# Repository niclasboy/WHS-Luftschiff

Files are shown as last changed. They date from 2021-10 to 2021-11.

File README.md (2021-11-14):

# WHS-Luftschiff

Dieses Projekt dokumentiert den Bau eines Starrluftschiffes im Rahmen des Studienganges Elektrotechnik an der Westfälischen Hochschule Gelsenkirchen.

# Mechanik / Aufbau Luftschiff

Dass Luftschiff wird durch vier Motoren angetriebe. Die Motoren sind an Propellergondeln montiert. So lassen die Motoren um -+90° im Bezug zur Hauptachse bewegen. Dank der Motoren ist der Einsatz eines Leitwerkes nicht erforderlich, da die hinteren zwei Motoren diese Aufgabe übernehmen können. Auch können alle Motoren senkrecht zum Luftschiff geneigt werden(90°). Dies kann dazu genutzt werden, um den Auftrieb zu erhöhen bzw. zu verringen. Im Falle eines Ausfalls der Funkverbindung können so die Motoren automatisch senkrecht zum Luftschiff geneigt werden, um das Luftschiff zum sinken zu "zwingen". 

Das Luftschiff besteht aus einem Holzgerippe, welches mit einer dünnen Folie luftdicht verschlossen ist. Um die dichtigkeit weiter zu steigen, beinhaltet das Luftschiff einen innen Körper, welcher später mit Helium/Ballongas gefüllt wird. Dies hat zusätlcih den Vorteil, dass sich im Luftschiff reines Helium befindet.

# Elektronik / Flugsteuerung

https://github.com/niclasboy/Flugsteuerung

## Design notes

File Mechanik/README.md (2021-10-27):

Berechnung des Gewichts / Auftriebs:

-800 gr Luftschiffkonstruktion <br>
-20  gr Innenballon <br>
-160 gr Motoren + Aufhängnung <br>

+1100gr (1200 gr max) Auftrieb <br>
+-------------------------------------------+<br>
120gr für Akku, Flugsteuerung und Kabel

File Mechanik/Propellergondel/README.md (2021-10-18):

Dokumente für den Bau der Propellergondel .

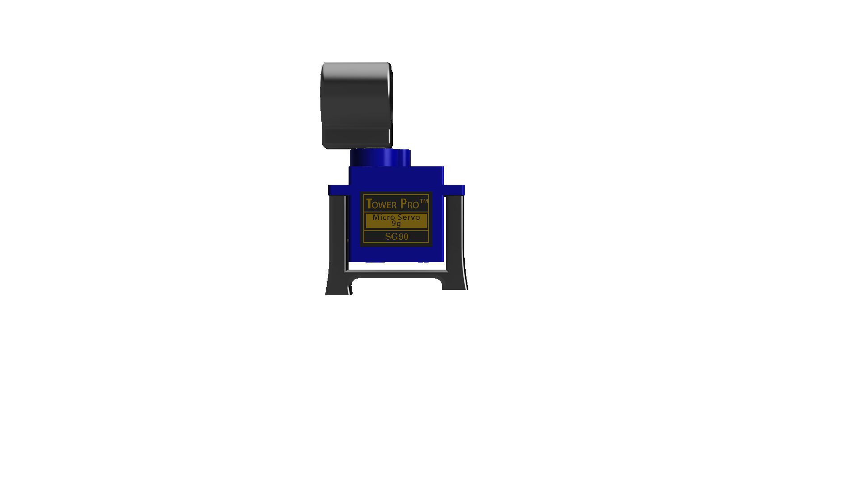
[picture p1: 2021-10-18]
Mechanik/Propellergondel/Bild2.png

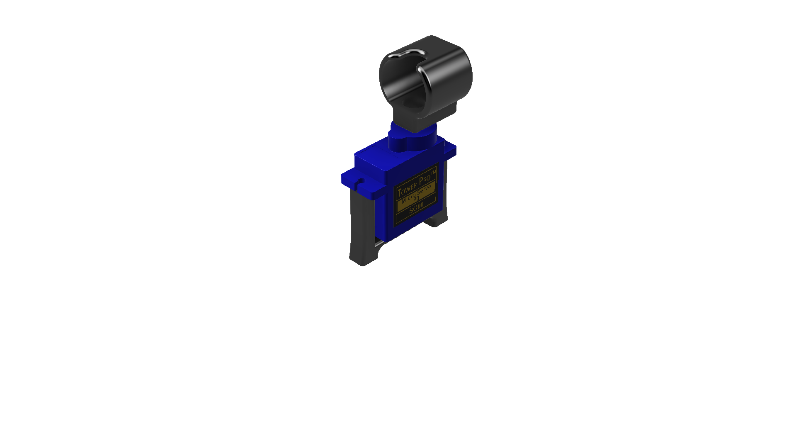
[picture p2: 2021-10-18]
Mechanik/Propellergondel/Bild3.png

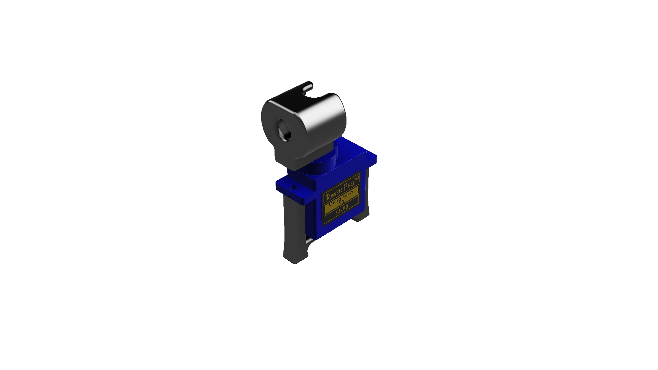
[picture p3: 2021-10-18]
Mechanik/Propellergondel/Bild 1.png

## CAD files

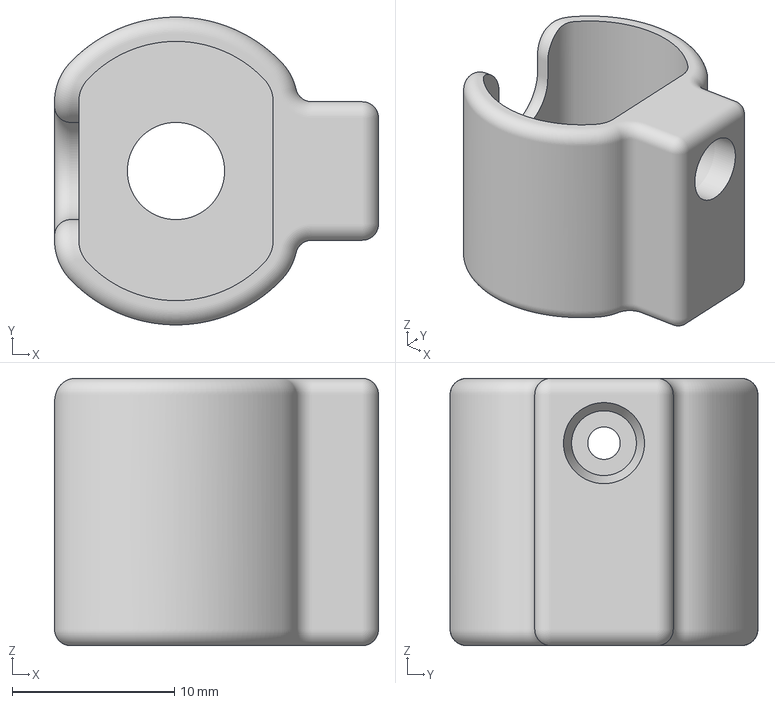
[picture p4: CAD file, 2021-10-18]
Mechanik/Propellergondel/Motorhalterung.3mf
20.0 x 19.0 x 16.5 mm

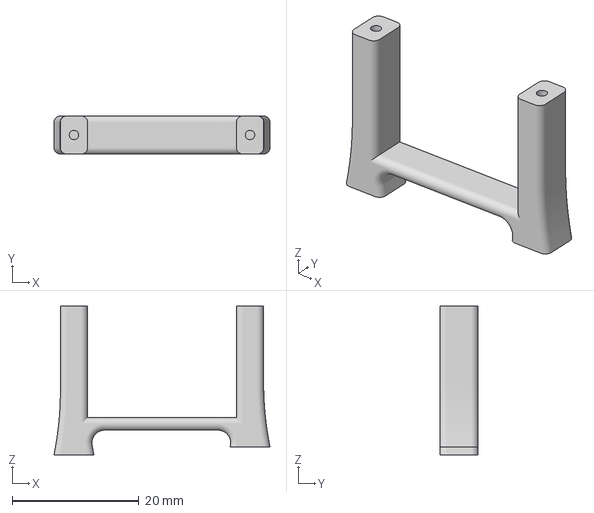
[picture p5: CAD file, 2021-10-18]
Mechanik/Propellergondel/Haupthalterung.3mf
34.1 x 6.00 x 23.5 mm

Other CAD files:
Mechanik/Propellergondel/Propellergondel .f3z

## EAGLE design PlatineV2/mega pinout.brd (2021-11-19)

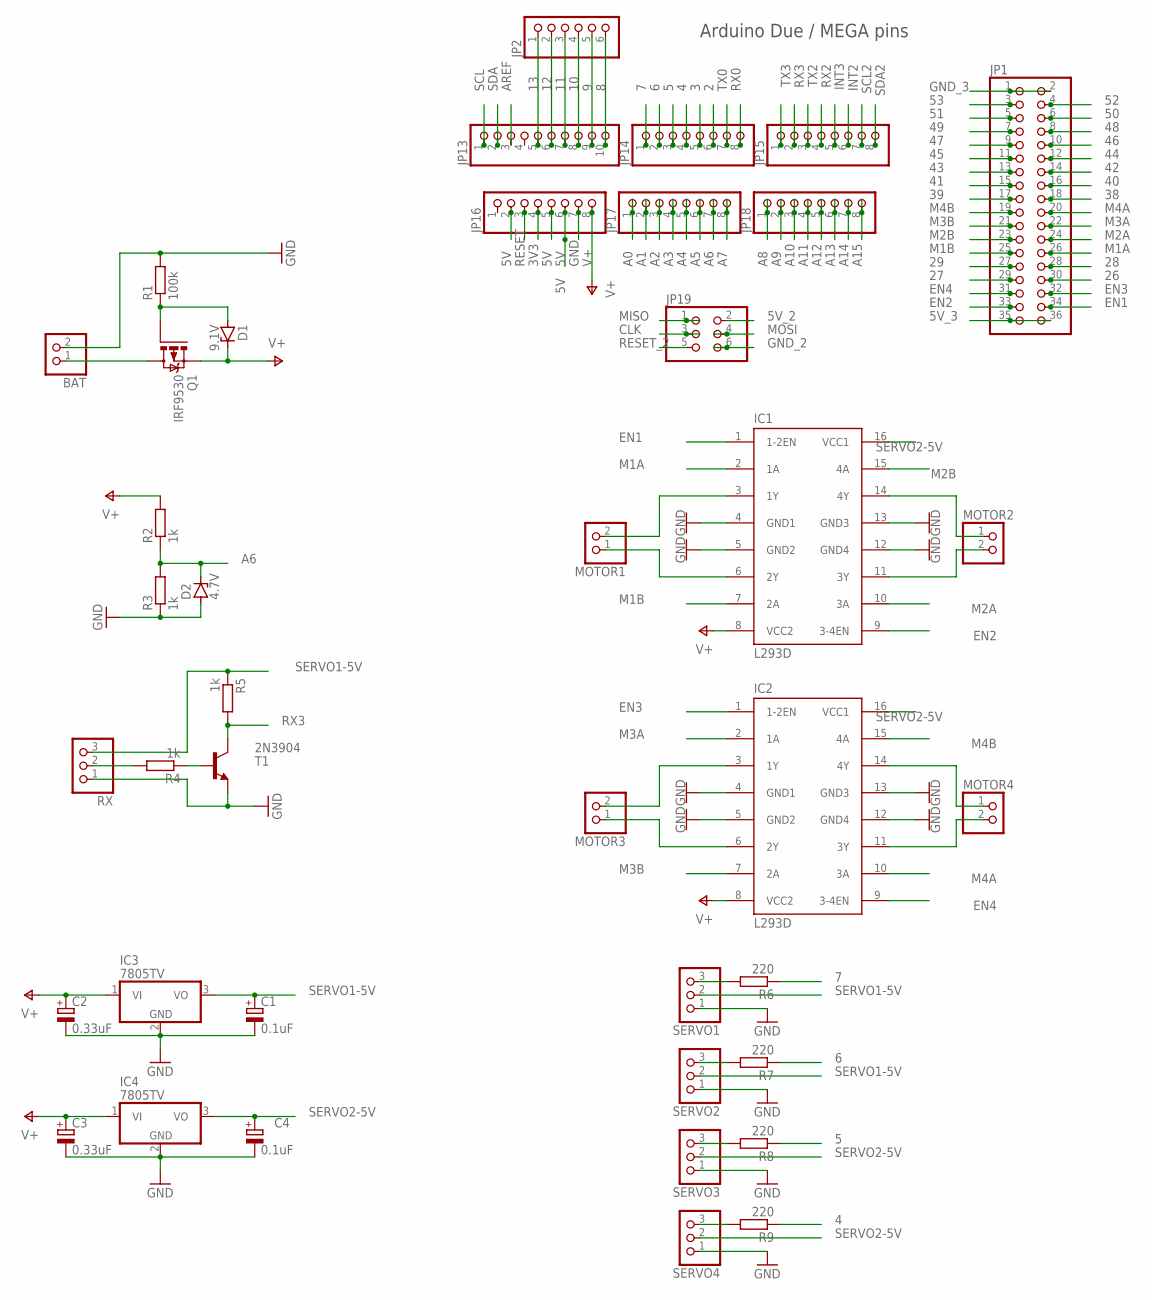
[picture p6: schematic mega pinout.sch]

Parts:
BAT: PINHD-1X2; 1X02
C1, C4: 0.1uF; E2,5-7
C2, C3: 0.33uF; E2,5-7
D1: 9.1V; ZDIO-2.5
D2: 4.7V; ZDIO-2.5
IC1, IC2: L293D; DIL16
IC3, IC4: 7805TV; TO220V
JP1: PINHD-2X18; 2X18
JP2: PINHD-1X6; 1X06
JP13: PINHD-1X10; 1X10
JP14, JP15, JP16, JP17, JP18: PINHD-1X8; 1X08
JP19: PINHD-2X3; 2X03
MOTOR1, MOTOR2, MOTOR3, MOTOR4: PINHD-1X2; 1X02
Q1: IRF9530; TO220BV
R1: 100k; 0207/2V
R2, R3, R4, R5: 1k; 0207/2V
R6, R7, R8, R9: 220; 0207/2V
RX: PINHD-1X3; 1X03
SERVO1, SERVO2, SERVO3, SERVO4: PINHD-1X3; 1X03
T1: 2N3904; TO92

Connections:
2: JP14.6
3: JP14.5
3V3: JP16.4
4: JP14.4, R9.1
5: JP14.3, R8.1
5V: JP16.2, JP16.5, JP16.6
5V_2: JP19.2
5V_3: JP1.35, JP1.36
6: JP14.2, R7.1
7: JP14.1, R6.1
8: JP2.6, JP13.10
9: JP2.5, JP13.9
10: JP2.4, JP13.8
11: JP2.3, JP13.7
12: JP2.2, JP13.6
13: JP2.1, JP13.5
26: JP1.30
27: JP1.29
28: JP1.28
29: JP1.27
38: JP1.18
39: JP1.17
40: JP1.16
41: JP1.15
42: JP1.14
43: JP1.13
44: JP1.12
45: JP1.11
46: JP1.10
47: JP1.9
48: JP1.8
49: JP1.7
50: JP1.6
51: JP1.5
52: JP1.4
53: JP1.3
A0: JP17.1
A1: JP17.2
A2: JP17.3
A3: JP17.4
A4: JP17.5
A5: JP17.6
A6: D2.C, JP17.7, R2.1, R3.2
A7: JP17.8
A8: JP18.1
A9: JP18.2
A10: JP18.3
A11: JP18.4
A12: JP18.5
A13: JP18.6
A14: JP18.7
A15: JP18.8
AREF: JP13.3
CLK: JP19.3
EN1: IC1.1 (1-2EN), JP1.34
EN2: IC1.9 (3-4EN), JP1.33
EN3: IC2.1 (1-2EN), JP1.32
EN4: IC2.9 (3-4EN), JP1.31
GND: BAT.2, C1.-, C2.-, C3.-, C4.-, D2.A, IC1.4 (GND1), IC1.5 (GND2), IC1.12 (GND4), IC1.13 (GND3), IC2.4 (GND1), IC2.12 (GND4), IC3.2 (GND), IC4.2 (GND), JP16.7, R1.2, R3.1, RX.1, SERVO1.1, SERVO2.1, SERVO3.1, SERVO4.1, T1.3 (E)
GND_2: JP19.6
GND_3: JP1.1, JP1.2
INT2: JP15.6
INT3: JP15.5
M1A: IC1.2 (1A), JP1.26
M1B: IC1.7 (2A), JP1.25
M2A: IC1.10 (3A), JP1.24
M2B: IC1.15 (4A), JP1.23
M3A: IC2.2 (1A), JP1.22
M3B: IC2.7 (2A), JP1.21
M4A: IC2.10 (3A), JP1.20
M4B: IC2.15 (4A), JP1.19
MISO: JP19.1
MOSI: JP19.4
MOTOR3: IC2.6 (2Y), MOTOR3.1
unnamed: IC1.3 (1Y), MOTOR1.2
unnamed: IC1.6 (2Y), MOTOR1.1
unnamed: IC1.11 (3Y), MOTOR2.2
unnamed: IC1.14 (4Y), MOTOR2.1
unnamed: IC2.3 (1Y), MOTOR3.2
unnamed: R4.2, RX.2
unnamed: IC2.11 (3Y), MOTOR4.2
unnamed: IC2.14 (4Y), MOTOR4.1
unnamed: BAT.1, Q1.D
unnamed: D1.A, Q1.G, R1.1
unnamed: R4.1, T1.2 (B)
unnamed: R7.2, SERVO2.3
unnamed: R6.2, SERVO1.3
unnamed: R8.2, SERVO3.3
unnamed: R9.2, SERVO4.3
RESET: JP16.3
RESET_2: JP19.5
RX0: JP14.8
RX2: JP15.4
RX3: JP15.2, R5.2, T1.1 (C)
SCL: JP13.1
SCL2: JP15.7
SDA: JP13.2
SDA2: JP15.8
SERVO1-5V: C1.+, IC3.3 (VO), R5.1, RX.3, SERVO1.2, SERVO2.2
SERVO2-5V: C4.+, IC1.16 (VCC1), IC2.16 (VCC1), IC4.3 (VO), SERVO3.2, SERVO4.2
TX0: JP14.7
TX2: JP15.3
TX3: JP15.1
V+: C2.+, C3.+, D1.C, IC1.8 (VCC2), IC2.8 (VCC2), IC3.1 (VI), IC4.1 (VI), JP16.8, Q1.S, R2.2

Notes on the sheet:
Arduino Due / MEGA pins

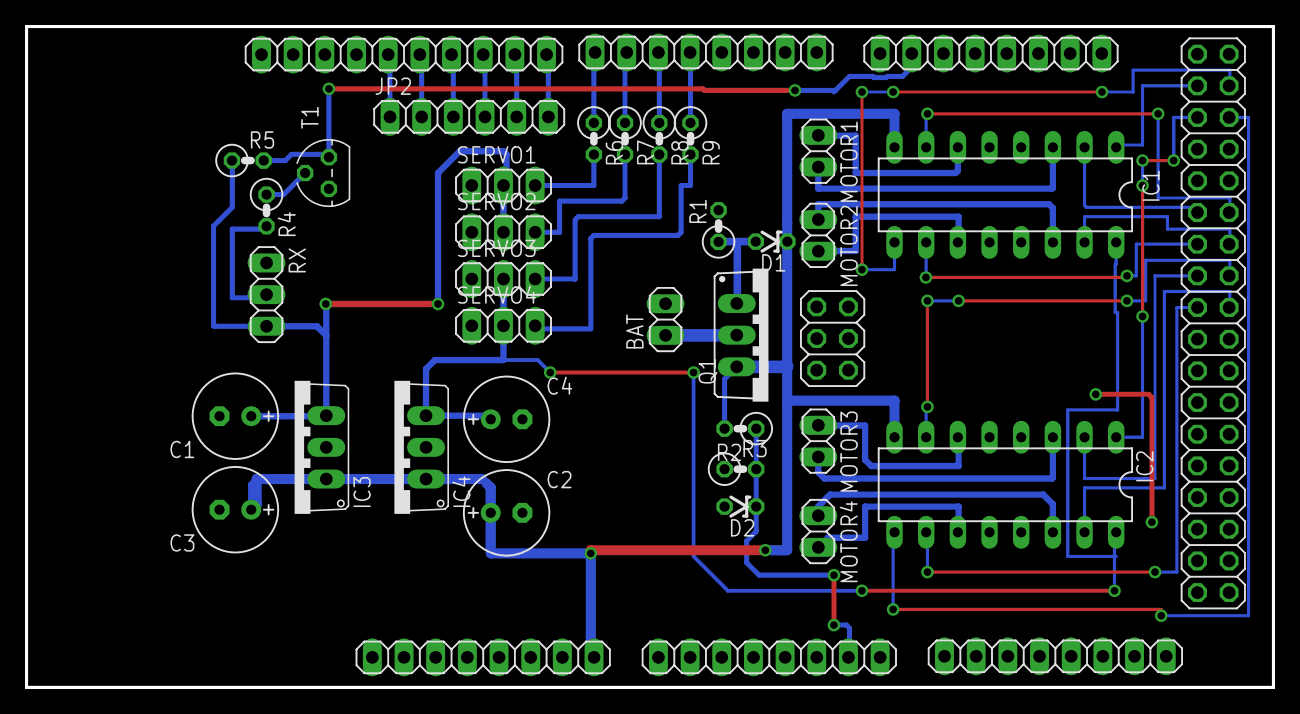
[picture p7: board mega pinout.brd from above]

Board: 2 copper layers, 100.0 x 53.0 mm, 40 parts (0 on the bottom side), 47 nets.

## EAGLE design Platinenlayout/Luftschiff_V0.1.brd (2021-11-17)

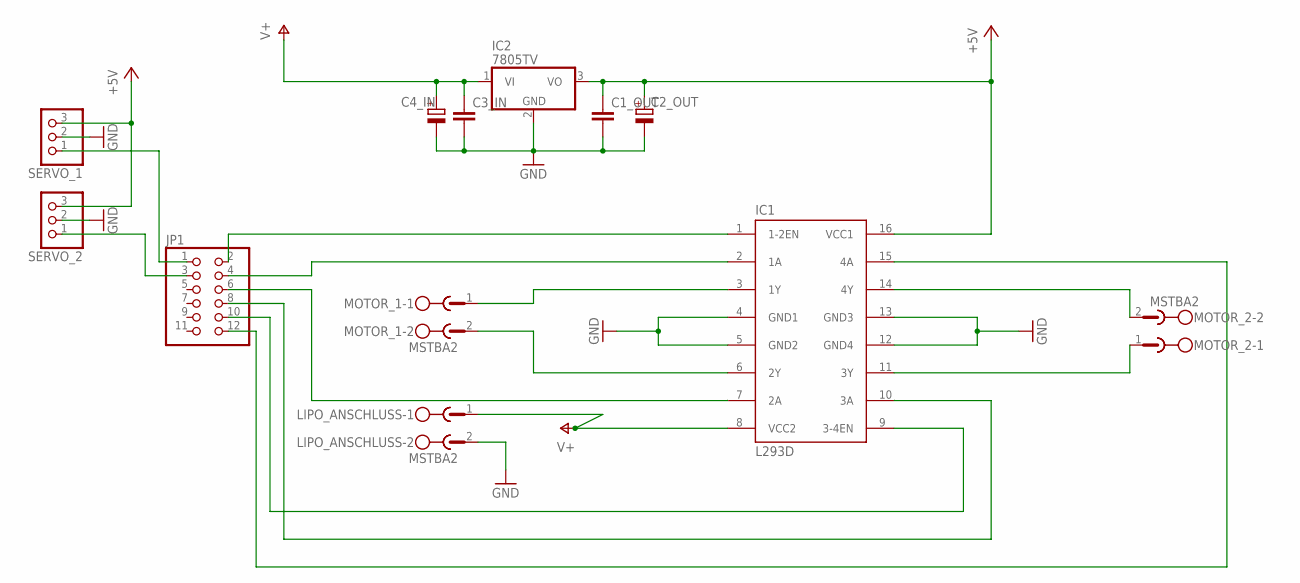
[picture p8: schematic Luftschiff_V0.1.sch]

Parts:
C1_OUT, C3_IN: C-EU025-040X050; C025-040X050
C2_OUT, C4_IN: CPOL-EUE2.5-6; E2,5-6
IC1: L293D; DIL16
IC2: 7805TV; TO220V
JP1: PINHD-2X6/90; 2X06/90
LIPO_ANSCHLUSS: MSTBA2
MOTOR_1, MOTOR_2: MSTBA2
SERVO_1, SERVO_2: PINHD-1X3; 1X03

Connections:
+5V: C1_OUT.1, C2_OUT.+, IC1.16 (VCC1), IC2.3 (VO), SERVO_1.3, SERVO_2.3
GND: C1_OUT.2, C2_OUT.-, C3_IN.2, C4_IN.-, IC1.4 (GND1), IC1.5 (GND2), IC1.12 (GND4), IC1.13 (GND3), IC2.2 (GND), LIPO_ANSCHLUSS.2, SERVO_1.2, SERVO_2.2
unnamed: JP1.1, SERVO_1.1
unnamed: JP1.3, SERVO_2.1
unnamed: IC1.11 (3Y), MOTOR_2.1
unnamed: IC1.14 (4Y), MOTOR_2.2
unnamed: IC1.3 (1Y), MOTOR_1.1
unnamed: IC1.6 (2Y), MOTOR_1.2
unnamed: IC1.1 (1-2EN), JP1.2
unnamed: IC1.2 (1A), JP1.4
unnamed: IC1.7 (2A), JP1.6
unnamed: IC1.10 (3A), JP1.8
unnamed: IC1.9 (3-4EN), JP1.10
unnamed: IC1.15 (4A), JP1.12
V+: C3_IN.1, C4_IN.+, IC1.8 (VCC2), IC2.1 (VI), LIPO_ANSCHLUSS.1

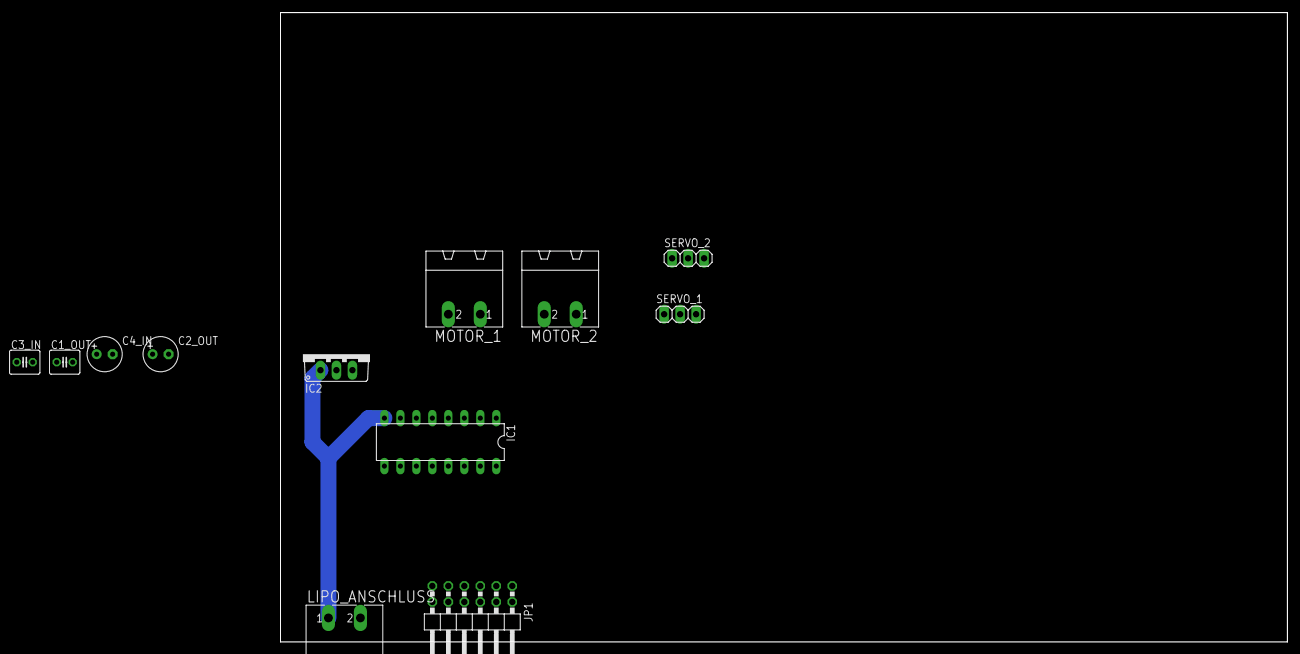
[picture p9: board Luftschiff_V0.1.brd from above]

Board: 2 copper layers, 160.0 x 100.0 mm, 12 parts (0 on the bottom side), 15 nets.

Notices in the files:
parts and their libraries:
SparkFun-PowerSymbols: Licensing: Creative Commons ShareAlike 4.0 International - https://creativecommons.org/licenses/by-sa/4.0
